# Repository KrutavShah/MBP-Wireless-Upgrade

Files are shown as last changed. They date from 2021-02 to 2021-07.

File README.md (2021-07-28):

# MBP-Wireless-Upgrade

A simple solution that allows you to upgrade your Unibody MacBook Pro wireless card to meet today's standards.

## So what is it?
This GitHub page contains schematics and models that you can use to buid your very own WiFi card to upgrade an Apple unibody MacBook Pro! (Not ready yet, but is coming soon.)
Macbooks manufactured prior to the 2nd half of 2012 like the 2011 MacBook Pro 15 inch include a WiFi + Bluetooth card that is considered to be lacking in functionality compared to today's standards. WiFi speed on these older cards top out at 450Mbps, which is a lot less than what most wireless routers are capable of today. In addition, the Bluetooth version is 3.0 on all models manufactured prior to 2012, something that may become problematic with newer devices and AirDrop.

## What is the progress so far?
Tthe Universal Adapter for all MacBooks is available for download and fabrication by downloadin the zip fle in the releases section. Upload it to JLCPCB and select the options that suit you best, such as your desired PCB thickness, PCB color, and specify the order number location so that it is printed where it's not visible. 

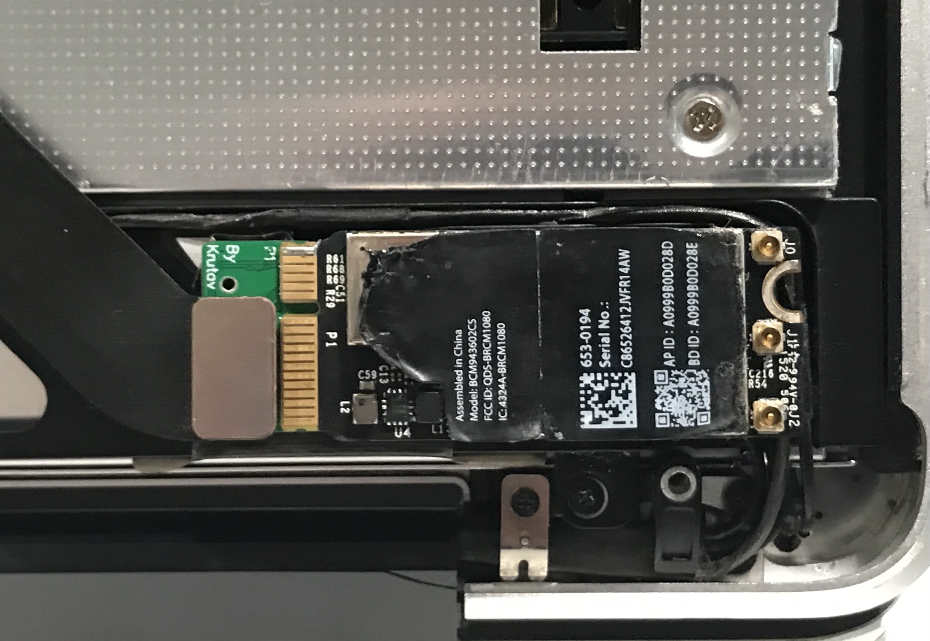
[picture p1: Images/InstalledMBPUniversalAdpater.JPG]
Picture of the MacBook Pro Universal Adapter inside a MacBook Pro 2011.

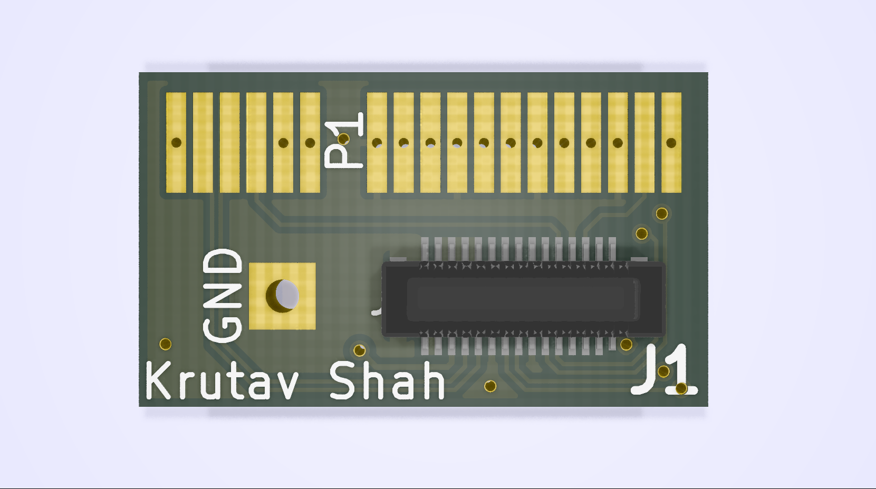
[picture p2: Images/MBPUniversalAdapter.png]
Picture of the MacBook Pro Universal Adapter.


## So why should you upgrade your MacBook if it is a decade old?
Well if you're like me and don't want to shell out a lot of money for one of Apple's new offerings, this upgrade can allow you to hold on to your MacBook for longer. With this upgrade, you get a newer version of Bluetooth 4 which allows you to use AirDrop and connect to most modern devices. You also get a much faster WiFi unit which can allow you to achieve speeds of over 1 Gigabit and take full potential of your home network.
The improvements:
- Access to 802.11 AC WiFi for speeds up to 1.3Gbps
- Up to Bluetooth 4.2 for improved range and speeds, as well as compatibility with more devices
- Newer technology, which means lower power consumption and better efficiency.
  
### Licensing information
This work is licensed under a
[Creative Commons Attribution-NonCommercial-NoDerivatives 4.0 International License][cc-by-nc-nd].

Distribution and modification of this project without giving proper credits is not allowed. For commercial usage of this project, the express permission of the project maintainer is necessary.

[][cc-by-nc-nd]

[cc-by-nc-nd]: http://creativecommons.org/licenses/by-nc-nd/4.0/
[cc-by-nc-nd-image]: https://licensebuttons.net/l/by-nc-nd/4.0/88x31.png

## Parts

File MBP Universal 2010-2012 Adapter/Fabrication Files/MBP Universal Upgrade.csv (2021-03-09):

Id | Designator | Package | Quantity | Designation | Supplier and ref
1 | J1 | 5017450301 | 1 | 501745-0301 | Molex
2 | P1 | Edge Connector | 1 | Edge Connector
3 | MH1 | MountingHole_2.2mm_M2_DIN965_Pad | 1 | GND Hole

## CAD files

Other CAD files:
Measurements/measurements.blend

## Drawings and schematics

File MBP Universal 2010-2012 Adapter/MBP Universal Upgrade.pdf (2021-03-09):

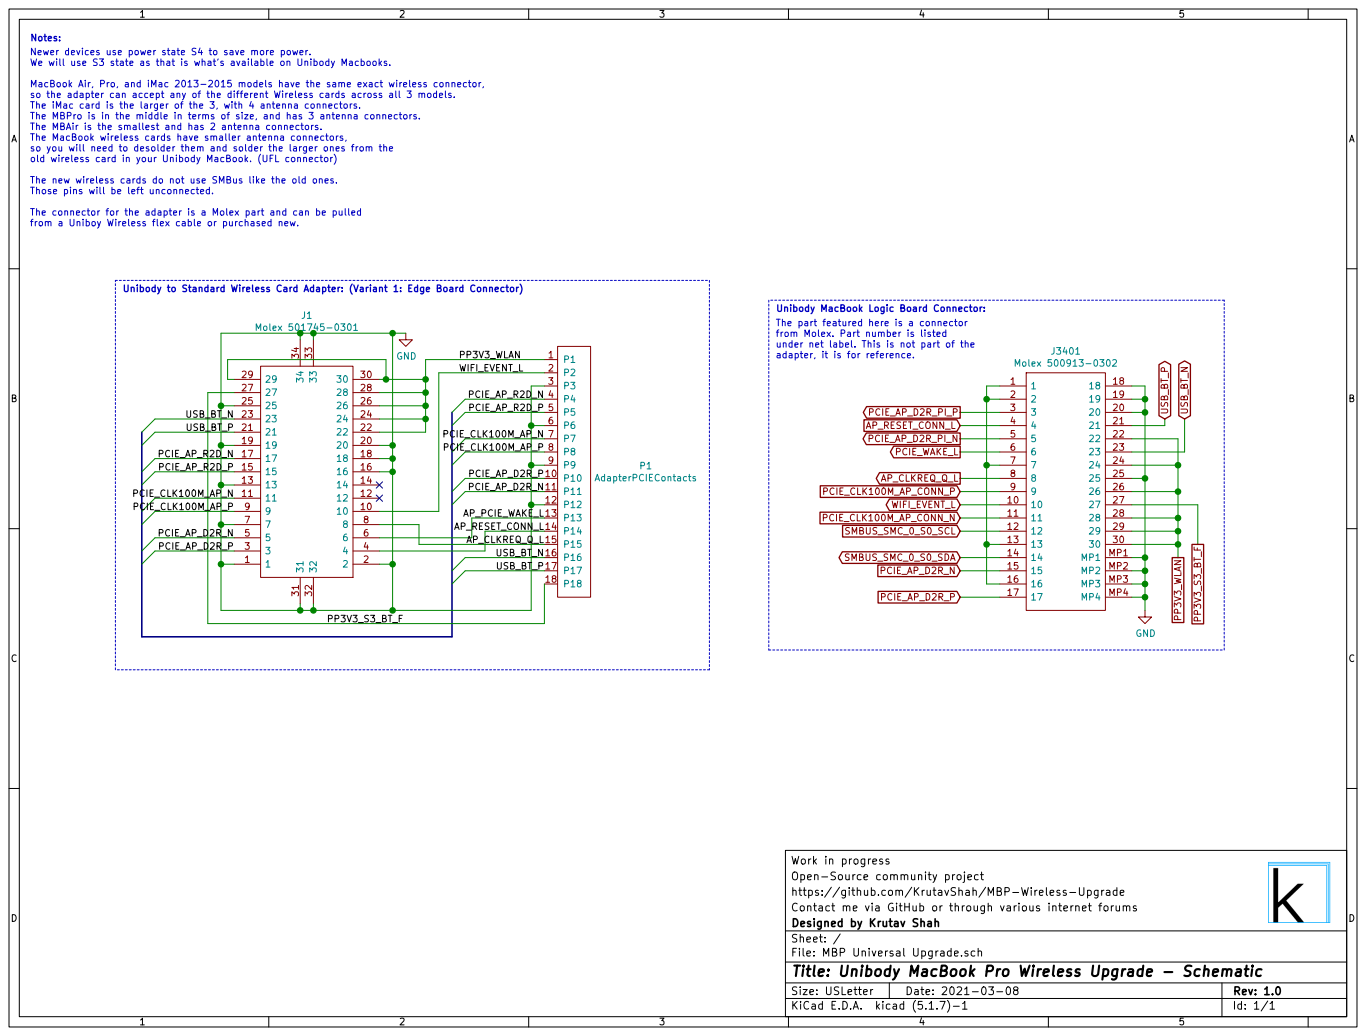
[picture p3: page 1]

Notes: Newer devices use power state S4 to save more power.

We will use S3 state as that is what's available on Unibody Macbooks. MacBook Air, Pro, and iMac 2013-2015 models have the same exact wireless connector, so the adapter can accept any of the different Wireless cards across all 3 models.

The iMac card is the larger of the 3, with 4 antenna connectors. The MBPro is in the middle in terms of size, and has 3 antenna connectors. The MBAir is the smallest and has 2 antenna connectors. The MacBook wireless cards have smaller antenna connectors, so you will need to desolder them and solder the larger ones from the

old wireless card in your Unibody MacBook. (UFL connector) The new wireless cards do not use SMBus like the old ones. Those pins will be left unconnected.

The connector for the adapter is a Molex part and can be pulled
from a Uniboy Wireless flex cable or purchased new.

Unibody to Standard Wireless Card Adapter: (Variant 1: Edge Board Connector)
AP_CLKREQ_Q_L WIFI_EVENT_L USB_BT_P

Unibody MacBook Logic Board Connector:
The part featured here is a connector
from Molex. Part number is listed
under net label. This is not part of the
adapter, it is for reference.

Work in progress
Open-Source community project
https://github.com/KrutavShah/MBP-Wireless-Upgrade
Contact me via GitHub or through various internet forums
File: MBP Universal Upgrade.sch Sheet: / Designed by Krutav Shah

Id: 1/1 Title: Unibody MacBook Pro Wireless Upgrade - Schematic

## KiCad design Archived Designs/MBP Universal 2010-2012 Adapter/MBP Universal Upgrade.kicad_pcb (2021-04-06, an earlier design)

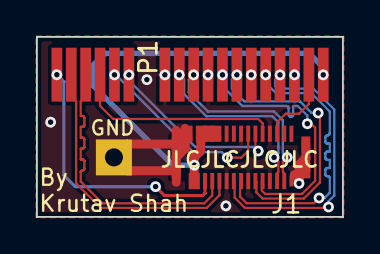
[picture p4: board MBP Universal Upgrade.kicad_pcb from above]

Board: 2 copper layers, 17.0 x 10.0 mm, 3 parts (0 on the bottom side), 15 nets.

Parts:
J1: Molex 501745-0301; 5017450301
MH1: GND Hole; MountingHole_2.2mm_M2_DIN965_Pad
P1: Edge Connector

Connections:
/AP_PCIE_WAKE_L: J1.12, P1.13
/PCIE_AP_R2D_N: J1.17, P1.4
/PCIE_AP_R2D_P: J1.15, P1.5
/PCIE_CLK100M_AP_N: J1.11, P1.7
/PCIE_CLK100M_AP_P: J1.9, P1.8
AP_CLKREQ_Q_L: J1.10, P1.15
AP_RESET_CONN_L: J1.14, P1.14
GND: J1.1, J1.7, J1.8, J1.13, J1.16, J1.19, J1.30, J1.31, J1.32, J1.33, J1.34, MH1.1, P1.3, P1.6, P1.9, P1.12
PCIE_AP_D2R_N: J1.5, P1.11
PCIE_AP_D2R_P: J1.3, P1.10
PP3V3_S3_BT_F: J1.25, P1.18
PP3V3_WLAN: J1.22, J1.24, J1.26, J1.27, J1.28, J1.29, P1.1
USB_BT_N: J1.23, P1.16
USB_BT_P: J1.21, P1.17
WIFI_EVENT_L: J1.6, P1.2

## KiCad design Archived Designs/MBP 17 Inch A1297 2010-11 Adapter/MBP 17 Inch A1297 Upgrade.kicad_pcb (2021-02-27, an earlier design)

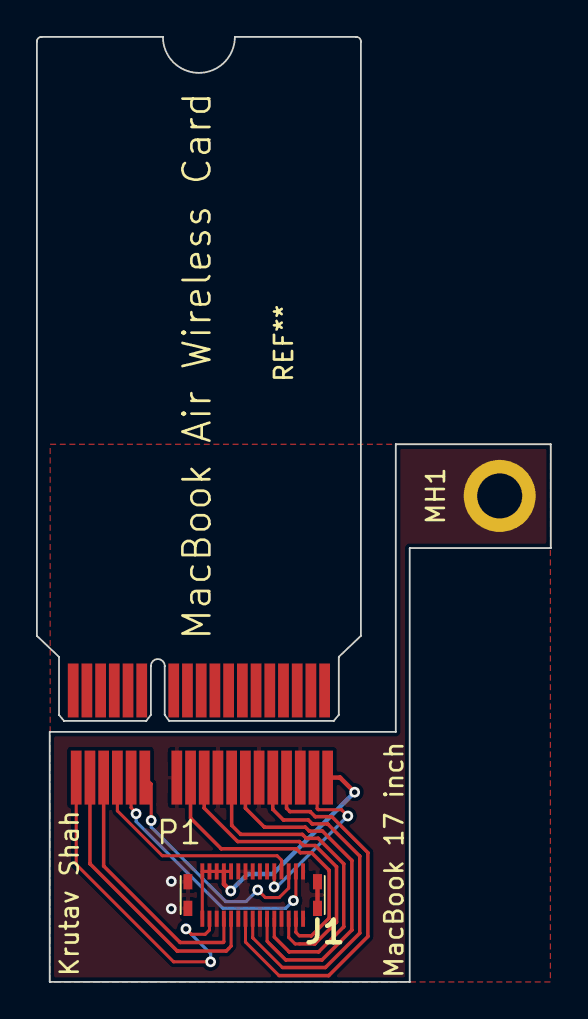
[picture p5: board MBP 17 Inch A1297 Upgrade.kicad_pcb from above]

Board: 2 copper layers, 28.5 x 52.5 mm, 3 parts (0 on the bottom side), 15 nets.

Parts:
J1: 501745-0301; 5017450301
MH1: MountingHole_2.5mm_Pad
P1: (no value)

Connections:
AP_CLKREQ_Q_L: J1.8, P1.15
AP_PCIE_WAKE_L: J1.6, P1.13
AP_RESET_CONN_L: J1.4, P1.14
GND: J1.1, J1.2, J1.7, J1.13, J1.16, J1.18, J1.19, J1.20, J1.25, J1.31, J1.32, J1.33, J1.34, MH1.1, P1.3, P1.6, P1.9, P1.12
PCIE_AP_D2R_N: J1.5, P1.10
PCIE_AP_D2R_P: J1.3, P1.11
PCIE_AP_R2D_N: J1.17, P1.4
PCIE_AP_R2D_P: J1.15, P1.5
PCIE_CLK100M_AP_N: J1.11, P1.7
PCIE_CLK100M_AP_P: J1.9, P1.8
PP3V3_S3_BT_F: J1.27, P1.18
PP3V3_WLAN: J1.22, J1.24, J1.26, J1.28, J1.29, J1.30, P1.1
USB_BT_N: J1.23, P1.16
USB_BT_P: J1.21, P1.17
WIFI_EVENT_L: J1.10, P1.2

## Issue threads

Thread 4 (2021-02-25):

MBP 13 mid 2012

pskowronek, 2021-02-25:
Hi!

Very nice project, I'm glad that you made it open-source!
I have a question about MBP 13 mid 2012 - I see some files regarding MBP 15, will they be OK for 13"? If not, are you going to provide some designs for 13"?

Thanks in advance!

KrutavShah, 2021-02-25:
My goal is to make one design that works for both models, but the problem I am seeing is that the screw holes and sizing is much more constrained. I don't own a 13 inch model so I would have to find someone that can provide measurements or borrow the laptop from someone.

pskowronek, 2021-02-25:
I can help you with measurements I guess

KrutavShah, 2021-02-25:
So I took a look and it appears that space is very much constrained in the 13 inch. The problem is that the wireless card assembly also holds the screw hole for the bottom shell of the MacBook. If I can find a solution for that, then this should be relatively straightforward.

pskowronek, 2021-02-25:
Personally I think this one screw missing won't make any difference :) so anything that is easier to retrofit is better. Latter on, maybe somebody having this macbook and right tools will be able to prepare more advanced design.

(I assume you saw it, just in case: https://www.ifixit.com/Guide/MacBook+Pro+13-Inch+Unibody+Mid+2012+AirPort-Bluetooth+Board+Replacement/10363)

KrutavShah, 2021-02-25:
That bracket does provide a level of structure for the right side of the MacBook and holds in the wires.

At the end of the day, it's the person who is making this upgrade for their laptop that can choose whether they want the bracket or not, so if you dont want the bracket there, feel free to leave it out. The design for the actual upgrade will be the same regardless.

With that out of the way, is there anything else we can discuss about the 13 inch MacBooks? My current focus is on the 15 inch.

pskowronek, 2021-02-25:
So, basically, if wanted to upgrade MBP 13" is the procedure more or less the same as for 15"? The same card from newer macbooks and the board to properly connect antennas and wires?

KrutavShah, 2021-02-26:
I believe only iMac wireless cards have the matching U.FL antenna connectors. This means that they will work right out of the box with the Unibody antennas. Only downside is that this card is the most expensive and largest one out of the other options. The MacBook Air and Pro wireless cards have the slightly smalled antenna connector, and while it may be possible to fit the U.FL antenna on there, it wont be as good of a connection. Instead, you're better off desoldering them and replacing them with the correct connectors by pulling them off the old wireless card.

As for the card itself, we are trying to find the connector for the card but haven't had any luck yet, which means for now, you will have to actually solder the wireless card onto the adapter. If you have a soldering iron and hot air gun designed for soldering and electronics work, that shouldn't be too much of a problem. An example of this is the 862D+ which is one of the cheapest electronics rework stations.

Because this is being given out in the form of a file that you send to PCB manufacturer, you're going to have to build it yourself or find someone who is willing to, so it's not an out of the box solution.

Closed 2021-06-17.

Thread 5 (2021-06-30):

Use of other Wifi Cards

satmandu, 2021-06-30:
Are there any specs on the older connecter, and specs for your new connector?

I'm trying to figure out if I can put a much newer wifi card in there, such as something which might support Wifi 6 or Wifi 6E.

KrutavShah, 2021-06-30:
The one in this project is the 12+6 pin proprietary connector used by Apple with Broadcom wireless cards made up to 2015. This means 802.11 AC and BT 4.2 are available on the newest of this particular line of wireless cards.

As far as I know, all the newer Macs use a soldered-on wireless chipset. This could mean that Apple WiFi 6 chipsets may be unavailable on a modular card.

satmandu, 2021-06-30:
So your adapter converts the old connector to act like the newer 12+6 proprietary connector?

I guess my question is this. What is the female connector the stock BCM943224PCIEBT2 cards go into called? And is there a way to make newer non Broadcom cards go into that slot, perhaps with an adapter. Maybe some way to get NGFF M.2 cards in there?

(I have linux on my old MacBookAir4,2, which works wonderfully, but I'd like to get a newer wifi card in there... and if a newer card can be made to work in that slot which linux supports, why settle for cards only made until 2015?)

satmandu, 2021-06-30:
For instance, it is some flavor of PCI-E, right, so something like this comes to mind: https://www.newegg.com/p/0XM-0555-00008?Description=ax210&cm_re=ax210-_-9SIAP7NE2J3525-_-Product

KrutavShah, 2021-07-01:
I see, so are you looking for the MacBook 12+6 pin to M.2 connector?

satmandu, 2021-07-01:
I think most wifi cards for laptops today use M.2 connectors. But since mini-PCIe/mPCIe to M.2 Adaptors exist as per the above link, I guess one question is whether the mini-pcie connector in the older mac laptops (what you call the 12+6 pin connector) is actually electrically compatible with some mini-PCIe standard.

Since you have designed this adaptor, do you know if that is the case? IIRC Apple has often used connector form factors which differ electrically from what other manufacturers have done with some connector form factors later on. (e.g. the connectors for SSDs in 2014 which were non-standard.)

satmandu, 2021-07-01:
Another site with mPCIe devices: https://www.assured-systems.com/us/news/article/what-are-mini-pci-express-mpcie-cards/

KrutavShah, 2021-07-06:
The goal of this project is to get newer wireless cards made by Apple in their older MacBooks. Since most M.2 and mPCIE cards are not MacOS capable, it's outside the scope of this project.

However it is possible, and you certainly can make your own adapter, taking from this project. The issue you will run into is spacing, but it is certainly possible. I think the 2015 wireless AC cards would be good enough for most use cases, but you can always use some of the components in this project's library if you really do need to make something more advanced.

satmandu, 2021-07-06:
Thanks. I would suggest expanding the scope of the project since macos is losing support on (I think) most of these older devices won't be supported with macos Monterey, since that will only support:
- MacBook Pro (early 2015 and later)
- MacBook Air (early 2015 and later)
- MacBook (early 2016 and later)

(But linux support seems fantastic on these older devices.)

Do you know if the mPCIE ports on these older laptops are standard compared to those found in non-apple devices, or if there is any special Apple sauce to them?

I guess I'll ask on the macrumors forums too...

KrutavShah, 2021-11-23:
So on Unibody MacBooks, a flex cable is used to connect to the WiFi card, which this adapter can take in and break out into a layout that was designed to work with WiFi cards in Macs up to 2015, which means the Broadcom 943602 chipset and is supported in MacOS Monterey without issue.

As far as expanding the project, I am making a Mini PCIe version of it so that these retina wireless cards can fit into a PC's Mini PCIe slot, though it's still being planned. Since Apple now solders all their WiFi cards in the newer MacBooks, there likely will be no way for this project to be upgraded to the new WiFi 6 (AX) standard that the latest Macs use. This should be fine however since the WiFi 5 (AC) cards used in Macs haven't changed too much after the Retina MacBooks that had detachable cards.

Now if you really did want something like this for WiFi AX, the chipset will need to be both supported by MacOS and use the PCIe interface, as well as the chip would need to be available for purchase. If BlueTooth uses UART on these newer models, it may be harder to make an adapter that will work fully. Looking at the latest 2021 MacBook Pros, it seems that they use PCIe for wireless which is normal, and UART for BlueTooth. I suppose if there is interest, some research can be put into making such an adapter.

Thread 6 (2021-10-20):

Using a 12+6 pin connector?

soleera, 2021-10-20:
Do you think it would be possible to use a 12+6 pin connector (e.g. https://www.aliexpress.com/item/1005002353470697.html) instead of soldering the wireless card on directly, or would this cause clearance issues with the case?

KrutavShah, 2022-03-30:
> Hi KrutavShah, could i ask you the part-number, the model or any reference about the connector used on the adapter? i can't find it.

Hello, the link for the connector has been shared in the previous comment made in this GitHub issue and it points to an Aliexpress product listing. Please take a look at that. Unfortunately, I don't have a part number because Apple uses their own internal part numbering for connectors like these that were custom-made for them.

Closed 2022-03-30.

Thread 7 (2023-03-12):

PCB Dimensions

hiarmen, 2023-03-12:
Hi Krutav,
I would like to put a card connector slot (instead of directly soldering card on PCB). However, no room for the card connector slot: footprints are too close. Is there a chance to update gerber - double up distance between soldering footprints?

KrutavShah, 2023-03-14:
> Hi Krutav, I would like to put a card connector slot (instead of directly soldering card on PCB). However, no room for the card connector slot: footprints are too close. Is there a chance to update gerber - double up distance between soldering footprints?

I think you may be able to solder on the connector at the edge of the PCB, but I haven't tried because I am not sure where you would obtain these connectors from in a bulk quantity. I am not entirely sure if I understand what you mean by increasing the distance between footprints. Did you mean increasing the distance between the flex cable socket connector and the wireless card footprint? I am not working on this project anymore, but if you would like to modify the design to accommodate a connector, you can certainly do so!

hiarmen, 2023-04-03:
Hi Krutav, thanks for reply. I managed to solder your way. However it was not easy. Would be better to use slot, but never mind. Thank for work!

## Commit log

2021-02-17 Initial KiCad files add
    [MBP 15 Inch A1286 Upgrade.kicad_pcb, MBP 15 Inch A1286 Upgrade.sch]
2021-02-24 Updated items
    [MBP 15 Inch A1286 Upgrade.kicad_pcb]
2021-02-26 Fixed broken files
    [MBP 15 Inch A1286 Upgrade.kicad_pcb, MBP 15 Inch A1286 Upgrade.kicad_sch, MBP 15 Inch A1286 Upgrade.sch]
2021-02-26 Added Wireless Card Connector
2021-02-27 Added 15-inch 1st revision
    [MBP 15 Inch A1286 Upgrade.kicad_pcb, MBP 15 Inch A1286 Upgrade.sch]
2021-02-27 Updated 2009 15-inch adapter
    [MBP 15 Inch A1286 Upgrade.kicad_pcb]
2021-02-27 Fixed model numbers
    [MBP 15 Inch A1286 Upgrade.kicad_pcb, MBP 15 Inch A1286 Upgrade.kicad_sch, MBP 15 Inch A1286 Upgrade.sch]
2021-02-27 Deleted temporary files and added images
    [MBP 17 Inch A1297 Upgrade.kicad_pcb, MBP 17 Inch A1297 Upgrade.kicad_sch]
2021-02-27 Updated board
    [MBP 17 Inch A1297 Upgrade.kicad_pcb]
2021-02-28 Added some measurements
    [measurements.blend]
2021-03-02 Renamed Folders
    [MBP 15 Inch A1286 Upgrade.kicad_pcb, MBP 15 Inch A1286 Upgrade.kicad_sch, MBP 15 Inch A1286 Upgrade.sch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]
2021-03-06 Updated the adapter
    [MBP 13 Inch A1278 Upgrade.kicad_pcb, MBP 13 Inch A1278 Upgrade.kicad_sch, MBP 13 Inch A1278 Upgrade.sch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]
2021-03-08 Release prototype for Universal part ready.
    [MBP Universal Upgrade.kicad_pcb, MBP Universal Upgrade.sch]
2021-03-09 Added pre-release fabrication files
    [MBP Universal Upgrade-B_Cu.gbr, MBP Universal Upgrade-B_Mask.gbr, MBP Universal Upgrade-B_SilkS.gbr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]
2021-03-09 Made updates for pre-release
    [MBP Universal Upgrade.kicad_pcb]
2021-04-04 Made large changes and fixes to the adapter
    [MBP 13 Inch A1278 Upgrade.kicad_pcb, MBP 13 Inch A1278 Upgrade.kicad_sch, MBP 13 Inch A1278 Upgrade.sch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]
2021-04-06 Matched trace lengths
    [MBP Universal Upgrade.kicad_pcb]
2021-06-17 Improved and redesigned in Altium.
    [MBP Universal Upgrade-B_Cu.gbr, MBP Universal Upgrade-B_Mask.gbr, MBP Universal Upgrade-B_SilkS.gbr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]
2021-07-28 Uploaded all updated files. This design is production ready and soon to be on Krutav.com
    [MBP Universal Upgrade.PcbDoc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]
